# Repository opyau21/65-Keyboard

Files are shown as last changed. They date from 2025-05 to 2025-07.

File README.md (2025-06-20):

# 65% Keyboard Project Files
## Summary
  Creating a 65% Keyboard from scratch without any prior engineering knowledge.

## Next steps:
  * Write Software for ESP32 S3 Mini 1 and STM32

## To Do List:
* PCB: Finished, not yet tested
* Software (In Order)
  1. Keymaps
  2. OLED
  3. Fuel Gauge
  4. Magnetic Encoder
  5. Bluetooth
* Plate
* Foam
* Knob plastics
* Case
  1. Design
  2. Backweight
  3. OLED Screen
* Battery
* Program Software QMK/VIA

## BOM:
| Item # | Reference | Qty | Manufacturer | Vendor | Mfg Part # | Value | Description/Value | Package | Datasheet |
| --- | --- | --- | --- | --- | --- | --- | --- | --- | --- |
| 1 | C1, C11, C2, C3, C4, C5, C9 | 6 | Murata Electronics | Mouser | GRM155R71C103KA01J | 100nF | Multilayer Ceramic Capacitors MLCC - SMD/SMT 0.01 uF 16 VDC 10% 0402 X7R | 402 | ~ |
| 2 | C10,C15 | 2 | Murata Electronics | Mouser | GRM155R60J475ME47J | 4.7uF | Multilayer Ceramic Capacitors MLCC - SMD/SMT 4.7 uF 6.3 VDC 20% 0402 X5R | 402 | ~ |
| 3 | C8,C16 | 2 | Murata Electronics | Mouser | GRM1555C2A101GA01D | 10uF | Multilayer Ceramic Capacitors MLCC - SMD/SMT 0402 10uF 4VDC 20% X6S AEC-Q200 | 402 | ~ |
| 4 | C14 | 1 | Murata Electronics | Mouser | GRM1555C2A101GA01D | 100pF | Multilayer Ceramic Capacitors MLCC - SMD/SMT 100 pF 100 VDC 2% 0402 C0G (NP0) | 402 | ~ |
| 5 | C17 | 1 | Murata Electronics | Mouser | GRM155R61A104KA01J | 0.1uF | Multilayer Ceramic Capacitors MLCC - SMD/SMT 0.1 uF 10 VDC 10% 0402 X5R | 402 | https://www.mouser.com/datasheet/2/281/1/GRM155R61A104KA01_02A-1983866.pdf |
| 6 | C6, C7 | 2 | Murata Electronics | Mouser | GXT155R60J105KE01D | 1uF | Multilayer Ceramic Capacitors MLCC - SMD/SMT 0402 6.3VDC 1uF 10% X5R AEC-Q200 | 402 | |
| 7 | C20,C21,C22,C23,C24,C25,C26,C27,C28,C29,C30,C31,C32,C33,C34,C35,C36,C37,C38,C39,C40,C41,C42,C43,C44,C45,C46,C47,C49,C50,C51,C52,C53,C54,C55,C56,C57,C58,C59,C60,C61,C62,C63,C64,C65,C66,C67,C68,C69,C70,C71,C72,C73,C74,C75,C76,C77,C78,C79,C80,C81,C82,C83,C84,C85,C86,C87 | 67  | Murata Electronics | Mouser | GCM188R71C104KA37J | 0.1uF | Multilayer Ceramic Capacitors MLCC - SMD/SMT 0.1 uF 16 VDC 10% 0603 X7R AEC-Q200 | 603 | ~ |
| 8 | D1,D2,D3,D4,D5,D6,D7,D8,D9,D10,D11,D12,D13,D14,D15,D16,D17,D18,D19,D20,D21,D22,D23,D24,D25,D26,D27,D28,D30,D31,D32,D33,D34,D35,D36,D37,D38,D39,D40,D41,D42,D43,D44,D45,D46,D47,D48,D49,D50,D51,D52,D53,D54,D55,D56,D57,D58,D59,D60,D61,D62,D63,D64,D65,D66,D67,D68 | 67  | | Adafruit | | D_Small | Adafruit Accessories 1N4148 SMT SOD-123 Diodes - 100 Pack | | ~ |
| 9 | J1 | 1 | | AliExpress | | Conn_01x02 | | | ~ |
| 10 | J2 | 1 | | AliExpress | | Conn_01x04 | | | ~ |
| 11 | J3 | 1 | | AliExpress | | Conn_01x07 | | | ~ |
| 12 | LED1,LED2,LED3,LED4,LED5,LED6,LED7,LED8,LED9,LED10,LED11,LED12,LED13,LED14,LED15,LED16,LED17,LED18,LED19,LED20,LED21,LED22,LED23,LED24,LED25,LED26,LED27,LED28,LED30,LED31,LED32,LED33,LED34,LED35,LED36,LED37,LED38,LED39,LED40,LED41,LED42,LED43,LED44,LED45,LED46,LED47,LED48,LED49,LED50,LED51,LED52,LED53,LED54,LED55,LED56,LED57,LED58,LED59,LED60,LED61,LED62,LED63,LED64,LED65,LED66,LED67,LED68 | 67  | | AliExpress | | LED_SK6812MINI | | | https://cdn-shop.adafruit.com/product-files/2686/SK6812MINI_REV.01-1-2.pdf |
| 13 | R1, R11, R12, R17, R3, R5 | 6 | YAGEO | Mouser | RC0402JR-7D10KL | 10k | Thick Film Resistors - SMD 10 kOhms 62.5 mW 0402 5% | 402 | ~ |
| 14 | R6,R7,R8,R9,R10 | 5 | YAGEO | Mouser | [RC0402FR-7D4K7L](https://www.mouser.com/ProductDetail/YAGEO/RC0402FR-7D4K7L?qs=F5EMLAvA7ID7%2FFIVczkChg%3D%3D) | 4.7k | Thick Film Resistors - SMD 4.7 kOhms 62.5 mW 0402 1% | 402 | ~ |
| 15 | R15 | 1 | YAGEO | Mouser | | 1k | | 402 | ~ |
| 16 | R16 | 1 | YAGEO | Mouser | | 750 | | 402 | ~ |
| 17 | S1,S2,S3,S4,S5,S6,S7,S8,S9,S10,S11,S12,S13,S14,S16,S17,S18,S19,S20,S21,S22,S23,S24,S25,S26,S27,S31,S32,S33,S34,S35,S36,S37,S38,S39,S40,S41,S42,S43,S44,S45,S46,S47,S48,S49,S50,S51,S52,S53,S54,S56,S57,S61,S64,S65,S66,S71,S72 | 58  | | Cannonkeys | | Keyswitch | Kailh MX Hotswap Sockets - 110 Pack | | ~ |
| 18 | S15,S28 | 2 | | | | Keyswitch | | | ~ |
| 19 | S30,S55 | 2 | | | | Keyswitch | | | ~ |
| 20 | S58,S59,S60,S62,S63 | 5 | | | | Keyswitch | | | ~ |
| 21 | S67 | 1 | | Divinikey | | MX_stab | TX Stabilizers | | |
| 22 | S68,S69 | 2 | | | | MX_stab | | | |
| 23 | S70 | 1 | | | | MX_stab | | | |
| 24 | SW1,SW2 | 2 | E-Switch | Mouser | TL3342F450QG | SW_Push | Tactile Switches 50mA 12VDC Silver Gull Wing | | ~ |
| 25 | U1 | 1 | [Analog Devices / Maxim Integrated](https://www.mouser.com/manufacturer/maxim-integrated/) | Mouser | MAX17048G+T10 | MAX17048G_T10 | Battery Management 3 A 1-Cell/2-Cell Fuel Gauge with ModelGauge | | |
| 26 | U2 | 1 | Semtech | Mouser | SRV05-4.TCT | SRV05-4 | ESD Protection Diodes / TVS Diodes RAILCLAMP 4-LINE 5V 3K LFREE | | http://www.onsemi.com/pub/Collateral/SRV05-4-D.PDF |
| 27 | U3 | 1 | Azoteq | Mouser | IQS6243200DNR | IQS624-3200-DNR | Board Mount Motion & Position Sensors 2 x Capacitive, Hall rotation | | |
| 28 | U4 | 1 | EspressIf | Mouser | ESP32-S3-MINI-1-N8 | ESP32-S3-MINI-1-N8 | Multiprotocol Modules SMD module, ESP32-S3FN8, 8 MB SPI flash, PCB antenna | | https://www.espressif.com/sites/default/files/documentation/esp32-s3-mini-1_mini-1u_datasheet_en.pdf |
| 29 | U5 | 1 | | Mouser | BQ25185DLHR | BQ25185DLHR | | | |
| 30 | U6 | 1 | STMicroelectronics | Mouser | STM32F103RET6TR | STM32F103RETx | ARM Microcontrollers - MCU 32BIT Cortex M3 H/D Performance LINE | | https://www.st.com/resource/en/datasheet/stm32f103re.pdf |
| 31 | U7 | 1 | UMW | Digikey | AMS1117-3.3 | AMS1117-3.3 | 3.3V LDO Regulator | | |
| 32 | F1 | 1 | Bourns | Mouser | MF-FSMF050X-2 | MF-FSMF050X-2 | Resettable Fuses - PPTC 6V .5A-HD 40A MAX | | |
| 33 | | 1 | | Amazon/AliExpress | | 5000 mah | 5000 mah Lithium Ion Recharable Battery | | |
| 34 | | 1 | | AliExpress | | 01x07 JST PH Wire  | 01x07 JST PH Wire | | |
| 35 | | 1 | aio3 | Cannonkeys | | | Unified Daughterboard | | |
| 36 | | 1 | Waveshare | Amazon | | 128 x 128 | 1.5 inch 128 x 128 RGB OLED Screen | | |
| 37 | | 1 | Logitech | AliExpress | | | Logitech MX Master 3s Side Scroll Component | | |

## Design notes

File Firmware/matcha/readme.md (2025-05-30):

# matcha

matcha

*A short description of the keyboard/project*

* Keyboard Maintainer: [Oliver Yau](https://github.com/opyau21)
* Hardware Supported: *The PCBs, controllers supported*
* Hardware Availability: *Links to where you can find this hardware*

Make example for this keyboard (after setting up your build environment):

    make matcha:default

Flashing example for this keyboard:

    make matcha:default:flash

See the [build environment setup](https://docs.qmk.fm/#/getting_started_build_tools) and the [make instructions](https://docs.qmk.fm/#/getting_started_make_guide) for more information. Brand new to QMK? Start with our [Complete Newbs Guide](https://docs.qmk.fm/#/newbs).

## Bootloader

Enter the bootloader in 3 ways:

* **Bootmagic reset**: Hold down the key at (0,0) in the matrix (usually the top left key or Escape) and plug in the keyboard
* **Physical reset button**: Briefly press the button on the back of the PCB - some may have pads you must short instead
* **Keycode in layout**: Press the key mapped to `QK_BOOT` if it is available

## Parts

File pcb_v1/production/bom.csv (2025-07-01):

Designator | Footprint | Quantity | Value | LCSC Part #
C1, C11, C2, C3, C4, C5, C9 | CAPC1005X55N | 7 | 100nF | C49678
C10, C15 | CAPC1005X55N | 2 | 4.7uF | C49678
C14 | CAPC1005X55N | 1 | 100pF | C49678
C16, C8 | CAPC1005X55N | 2 | 10uF | C49678
C17 | CAPC1005X55N | 1 | 0.1uF | C49678
C18, C19 | CAPC1005X55N | 2 | 1uF | C49678
C20, C21, C22, C23, C24, C25, C26, C27, C28, C29, C30, C31, C32, C33, C34, C35, C36, C37, C38, C39, C40, C41, C42, C43, C44, C45, C46, C47, C49, C50, C51, C52, C53, C54, C55, C56, C57, C58, C59, C60, C61, C62, C63, C64, C65, C66, C67, C68, C69, C70, C71, C72, C73, C74, C75, C76, C77, C78, C79, C80, C81, C82, C83, C84, C85, C86, C87 | CAPC1608X90N | 67 | 100nF
C6, C7 | CAPC1005X55N | 2 | 4.7uF
D1, D10, D11, D12, D13, D14, D15, D16, D17, D18, D19, D2, D20, D21, D22, D23, D24, D25, D26, D27, D28, D3, D30, D31, D32, D33, D34, D35, D36, D37, D38, D39, D4, D40, D41, D42, D43, D44, D45, D46, D47, D48, D49, D5, D50, D51, D52, D53, D54, D55, D56, D57, D58, D59, D6, D60, D61, D62, D63, D64, D65, D66, D67, D68, D7, D8, D9 | Diode_SOD-123 | 67 | D_Small
F1 | 0603 | 1 | 500mA
J1 | JST_PH_S2B-PH-SM4-TB_1x02-1MP_P2.00mm_Horizontal | 1 | Conn_01x02
J2 | JST_SH_SM04B-SRSS-TB_1x04-1MP_P1.00mm_Horizontal | 1 | Conn_01x04
J3 | JST_PH_S7B-PH-SM4-TB_1x07-1MP_P2.00mm_Horizontal | 1 | Conn_01x07
LED1, LED10, LED11, LED12, LED13, LED14, LED15, LED16, LED17, LED18, LED19, LED2, LED20, LED21, LED22, LED23, LED24, LED25, LED26, LED27, LED28, LED3, LED30, LED31, LED32, LED33, LED34, LED35, LED36, LED37, LED38, LED39, LED4, LED40, LED41, LED42, LED43, LED44, LED45, LED46, LED47, LED48, LED49, LED5, LED50, LED51, LED52, LED53, LED54, LED55, LED56, LED57, LED58, LED59, LED6, LED60, LED61, LED62, LED63, LED64, LED65, LED66, LED67, LED68, LED7, LED8, LED9 | LED_SK6812MINI | 67 | LED_SK6812MINI | C5149201
R1, R11, R12, R17, R2, R3, R4, R5 | RESC1005X40N | 8 | 10k
R10, R6, R7, R8, R9 | RESC1005X40N | 5 | 4.7k
R15 | RESC1005X40N | 1 | 1k
R16 | RESC1005X40N | 1 | 750
S1, S10, S11, S12, S13, S14, S16, S17, S18, S19, S2, S20, S21, S22, S23, S24, S25, S26, S27, S3, S31, S32, S33, S34, S35, S36, S37, S38, S39, S4, S40, S41, S42, S43, S44, S45, S46, S47, S48, S49, S5, S50, S51, S52, S53, S54, S56, S57, S6, S61, S64, S65, S66, S7, S71, S72, S8, S9 | SW_MX_HS_CPG151101S11_1u | 58 | Keyswitch
S15, S28 | SW_MX_HS_CPG151101S11_1.5u | 2 | Keyswitch
S30, S55 | SW_MX_HS_CPG151101S11_1.75u | 2 | Keyswitch
S58, S59, S60, S62, S63 | SW_MX_HS_CPG151101S11_1.25u | 5 | Keyswitch
S67 | STAB_MX_P_2u | 1 | MX_stab
S68, S69 | STAB_MX_2.25u | 2 | MX_stab
S70 | STAB_MX_P_6.25u | 1 | MX_stab
SW1, SW2 | Button_TL3342 | 2 | SW_Push
U1 | SON50P200X200X80-9N | 1 | MAX17048G_T10
U2 | SOT-23-6 | 1 | SRV05-4 | C85364
U3 | SON50P300X300X80-11N | 1 | IQS624-3200-DNR
U4 | XCVR_ESP32-S3-MINI-1-N8 | 1 | ESP32-S3-MINI-1
U5 | WSON10_DLH_TEX | 1 | BQ25185DLHR
U6 | LQFP-64_10x10mm_P0.5mm | 1 | STM32F103RETx
U7 | SOT229P700X180-4N | 1 | AMS1117-3.3

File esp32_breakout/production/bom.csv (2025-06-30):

Designator | Footprint | Quantity | Value | LCSC Part #
3.3V, EN, GND1, GPIO0, RX, TX | TestPoint_THTPad_D2.0mm_Drill1.0mm | 6 | TestPoint
C8 | CAPC1005X55N | 1 | 10uF | C49678
C9 | CAPC1005X55N | 1 | 100nF | C49678
R1, R2 | RESC1005X40N | 2 | 10k
U4 | XCVR_ESP32-S3-MINI-1-N8 | 1 | ESP32-S3-MINI-1

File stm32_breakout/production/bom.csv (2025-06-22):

Designator | Footprint | Quantity | Value | LCSC Part #
3.3V, BOOT0, GND, NRST, RX, TX | TestPoint_THTPad_D2.0mm_Drill1.0mm | 6 | TestPoint
C1, C11, C2, C3, C4, C5 | CAPC1005X55N | 6 | 100nF | C49678
C10 | CAPC1005X55N | 1 | 4.7uF | C49678
R1, R12 | RESC1005X40N | 2 | 10k
U6 | LQFP-64_10x10mm_P0.5mm | 1 | STM32F103RETx

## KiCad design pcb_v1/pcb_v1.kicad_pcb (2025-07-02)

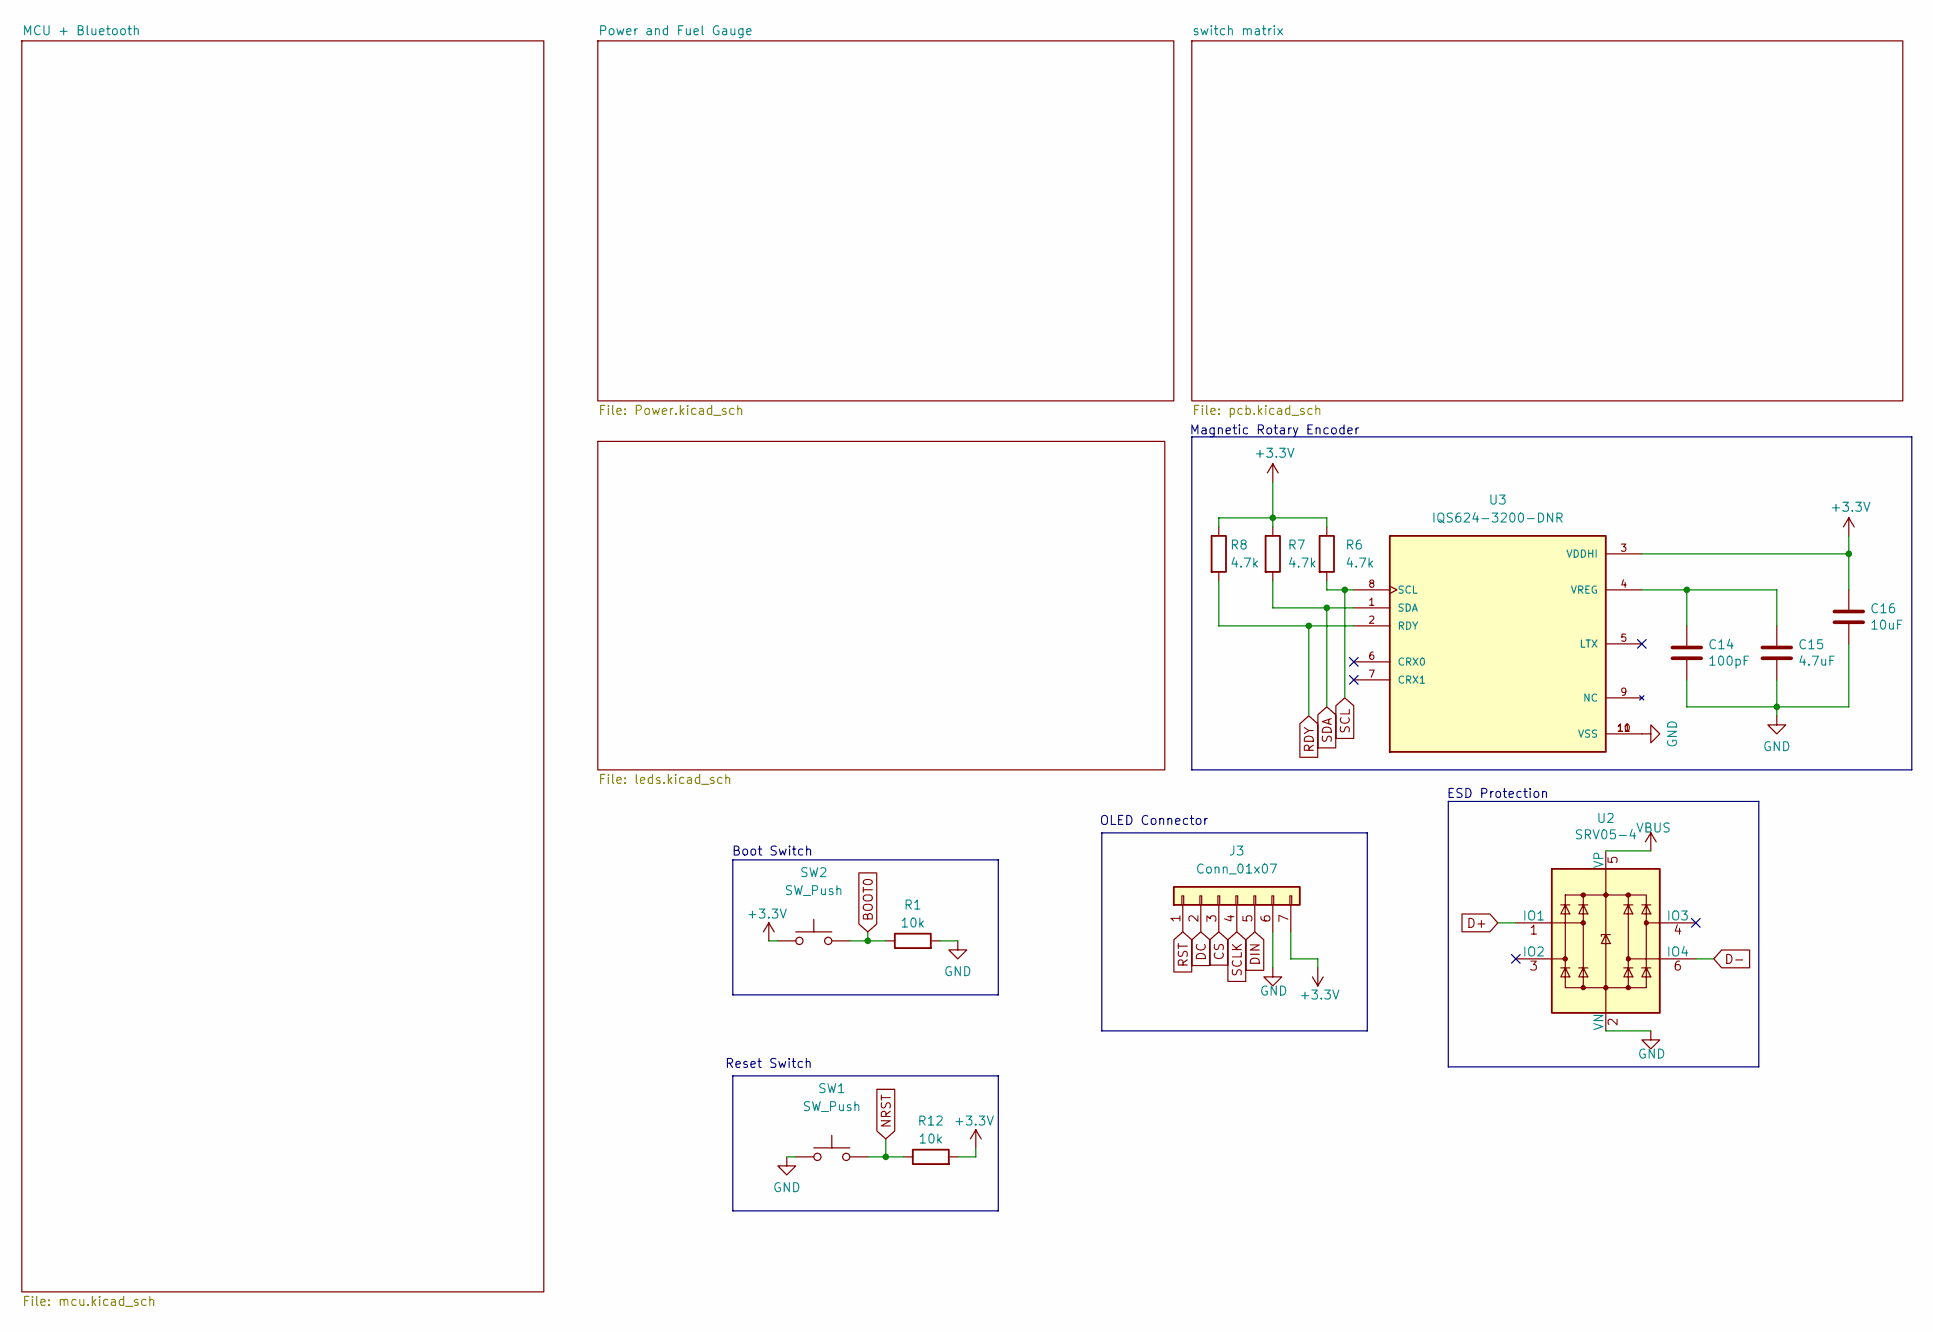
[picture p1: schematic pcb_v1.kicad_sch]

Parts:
C14: 100pF; CAPC1005X55N; LCSC Part # C49678
C15: 4.7uF; CAPC1005X55N; LCSC Part # C49678
C16: 10uF; CAPC1005X55N; LCSC Part # C49678
J3: Conn_01x07; JST_PH_S7B-PH-SM4-TB_1x07-1MP_P2.00mm_Horizontal
R1, R12: 10k; RESC1005X40N
R6, R7, R8: 4.7k; RESC1005X40N
SW1, SW2: SW_Push; Button_TL3342
U2: SRV05-4; SOT-23-6; LCSC Part # C85364
U3: IQS624-3200-DNR; SON50P300X300X80-11N; PARTREV 2.04

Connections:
+3.3V: C16.1, J3.7, R6.1, R7.1, R8.1, R12.2, SW2.1, U3.3 (VDDHI); also elsewhere on the board
BOOT0: R1.1, SW2.2; also elsewhere on the board
CS: J3.3; also elsewhere on the board
D+: U2.1 (IO1); also elsewhere on the board
D-: U2.6 (IO4); also elsewhere on the board
DC: J3.2; also elsewhere on the board
DIN: J3.5; also elsewhere on the board
GND: C14.2, C15.2, C16.2, J3.6, R1.2, SW1.1, U2.2 (VN), U3.10 (VSS), U3.11 (VSS); also elsewhere on the board
NRST: R12.1, SW1.2; also elsewhere on the board
unnamed: C14.1, C15.1, U3.4 (VREG)
RDY: R8.2, U3.2 (RDY); also elsewhere on the board
RST: J3.1; also elsewhere on the board
SCL: R6.2, U3.8 (SCL); also elsewhere on the board
SCLK: J3.4; also elsewhere on the board
SDA: R7.2, U3.1 (SDA); also elsewhere on the board
VBUS: U2.5 (VP); also elsewhere on the board

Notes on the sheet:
OLED Connector
Boot Switch
ESD Protection
Magnetic Rotary Encoder
Reset Switch

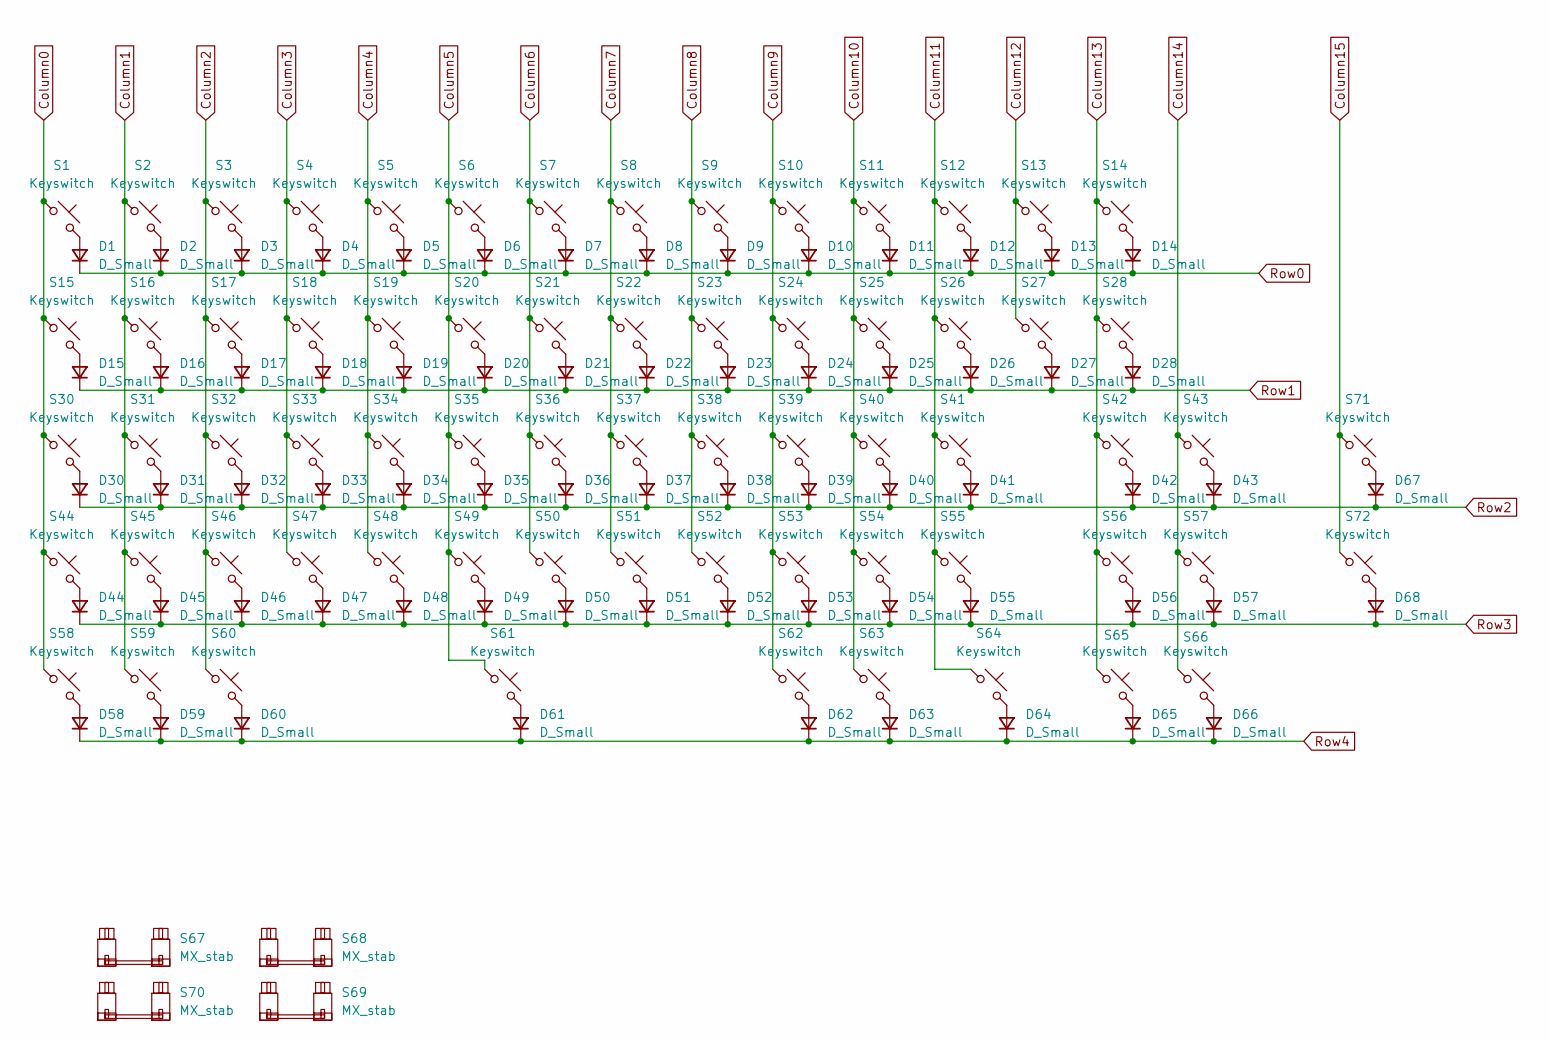
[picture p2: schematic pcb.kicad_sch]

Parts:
D1, D2, D3, D4, D5, D6, D7, D8, D9, D10, D11, D12, D13, D14, D15, D16, D17, D18, D19, D20, D21, D22, D23, D24, D25, D26, D27, D28, D30, D31, D32, D33, D34, D35, D36, D37, D38, D39, D40, D41, D42, D43, D44, D45, D46, D47, D48, D49, D50, D51, D52, D53, D54, D55, D56, D57, D58, D59, D60, D61, D62, D63, D64, D65, D66, D67, D68: D_Small; Diode_SOD-123
S1, S2, S3, S4, S5, S6, S7, S8, S9, S10, S11, S12, S13, S14, S16, S17, S18, S19, S20, S21, S22, S23, S24, S25, S26, S27, S31, S32, S33, S34, S35, S36, S37, S38, S39, S40, S41, S42, S43, S44, S45, S46, S47, S48, S49, S50, S51, S52, S53, S54, S56, S57, S61, S64, S65, S66, S71, S72: Keyswitch; SW_MX_HS_CPG151101S11_1u
S15, S28: Keyswitch; SW_MX_HS_CPG151101S11_1.5u
S30, S55: Keyswitch; SW_MX_HS_CPG151101S11_1.75u
S58, S59, S60, S62, S63: Keyswitch; SW_MX_HS_CPG151101S11_1.25u
S67: MX_stab; STAB_MX_P_2u
S68, S69: MX_stab; STAB_MX_2.25u
S70: MX_stab; STAB_MX_P_6.25u

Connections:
Column0: S1.1, S15.1, S30.1, S44.1, S58.1; also elsewhere on the board
Column1: S2.1, S16.1, S31.1, S45.1, S59.1; also elsewhere on the board
Column2: S3.1, S17.1, S32.1, S46.1, S60.1; also elsewhere on the board
Column3: S4.1, S18.1, S33.1, S47.1; also elsewhere on the board
Column4: S5.1, S19.1, S34.1, S48.1; also elsewhere on the board
Column5: S6.1, S20.1, S35.1, S49.1, S61.1; also elsewhere on the board
Column6: S7.1, S21.1, S36.1, S50.1; also elsewhere on the board
Column7: S8.1, S22.1, S37.1, S51.1; also elsewhere on the board
Column8: S9.1, S23.1, S38.1, S52.1; also elsewhere on the board
Column9: S10.1, S24.1, S39.1, S53.1, S62.1; also elsewhere on the board
Column10: S11.1, S25.1, S40.1, S54.1, S63.1; also elsewhere on the board
Column11: S12.1, S26.1, S41.1, S55.1, S64.1; also elsewhere on the board
Column12: S13.1, S27.1; also elsewhere on the board
Column13: S14.1, S28.1, S42.1, S56.1, S65.1; also elsewhere on the board
Column14: S43.1, S57.1, S66.1; also elsewhere on the board
Column15: S71.1, S72.1; also elsewhere on the board
unnamed: D1.2 (A), S1.2
unnamed: D2.2 (A), S2.2
unnamed: D3.2 (A), S3.2
unnamed: D4.2 (A), S4.2
unnamed: D5.2 (A), S5.2
unnamed: D6.2 (A), S6.2
unnamed: D7.2 (A), S7.2
unnamed: D8.2 (A), S8.2
unnamed: D9.2 (A), S9.2
unnamed: D10.2 (A), S10.2
unnamed: D11.2 (A), S11.2
unnamed: D12.2 (A), S12.2
unnamed: D13.2 (A), S13.2
unnamed: D14.2 (A), S14.2
unnamed: D15.2 (A), S15.2
unnamed: D16.2 (A), S16.2
unnamed: D17.2 (A), S17.2
unnamed: D18.2 (A), S18.2
unnamed: D19.2 (A), S19.2
unnamed: D20.2 (A), S20.2
unnamed: D21.2 (A), S21.2
unnamed: D22.2 (A), S22.2
unnamed: D23.2 (A), S23.2
unnamed: D24.2 (A), S24.2
unnamed: D25.2 (A), S25.2
unnamed: D26.2 (A), S26.2
unnamed: D27.2 (A), S27.2
unnamed: D28.2 (A), S28.2
unnamed: D30.2 (A), S30.2
unnamed: D31.2 (A), S31.2
unnamed: D32.2 (A), S32.2
unnamed: D33.2 (A), S33.2
unnamed: D34.2 (A), S34.2
unnamed: D35.2 (A), S35.2
unnamed: D36.2 (A), S36.2
unnamed: D37.2 (A), S37.2
unnamed: D38.2 (A), S38.2
unnamed: D39.2 (A), S39.2
unnamed: D40.2 (A), S40.2
unnamed: D41.2 (A), S41.2
unnamed: D42.2 (A), S42.2
unnamed: D43.2 (A), S43.2
unnamed: D44.2 (A), S44.2
unnamed: D45.2 (A), S45.2
unnamed: D46.2 (A), S46.2
unnamed: D47.2 (A), S47.2
unnamed: D48.2 (A), S48.2
unnamed: D49.2 (A), S49.2
unnamed: D50.2 (A), S50.2
unnamed: D51.2 (A), S51.2
unnamed: D52.2 (A), S52.2
unnamed: D53.2 (A), S53.2
unnamed: D54.2 (A), S54.2
unnamed: D55.2 (A), S55.2
unnamed: D56.2 (A), S56.2
unnamed: D57.2 (A), S57.2
unnamed: D58.2 (A), S58.2
unnamed: D59.2 (A), S59.2
unnamed: D60.2 (A), S60.2
unnamed: D61.2 (A), S61.2
unnamed: D62.2 (A), S62.2
unnamed: D63.2 (A), S63.2
unnamed: D64.2 (A), S64.2
unnamed: D65.2 (A), S65.2
unnamed: D66.2 (A), S66.2
unnamed: D67.2 (A), S71.2
unnamed: D68.2 (A), S72.2
Row0: D1.1 (K), D2.1 (K), D3.1 (K), D4.1 (K), D5.1 (K), D6.1 (K), D7.1 (K), D8.1 (K), D9.1 (K), D10.1 (K), D11.1 (K), D12.1 (K), D13.1 (K), D14.1 (K); also elsewhere on the board
Row1: D15.1 (K), D16.1 (K), D17.1 (K), D18.1 (K), D19.1 (K), D20.1 (K), D21.1 (K), D22.1 (K), D23.1 (K), D24.1 (K), D25.1 (K), D26.1 (K), D27.1 (K), D28.1 (K); also elsewhere on the board
Row2: D30.1 (K), D31.1 (K), D32.1 (K), D33.1 (K), D34.1 (K), D35.1 (K), D36.1 (K), D37.1 (K), D38.1 (K), D39.1 (K), D40.1 (K), D41.1 (K), D42.1 (K), D43.1 (K), D67.1 (K); also elsewhere on the board
Row3: D44.1 (K), D45.1 (K), D46.1 (K), D47.1 (K), D48.1 (K), D49.1 (K), D50.1 (K), D51.1 (K), D52.1 (K), D53.1 (K), D54.1 (K), D55.1 (K), D56.1 (K), D57.1 (K), D68.1 (K); also elsewhere on the board
Row4: D58.1 (K), D59.1 (K), D60.1 (K), D61.1 (K), D62.1 (K), D63.1 (K), D64.1 (K), D65.1 (K), D66.1 (K); also elsewhere on the board

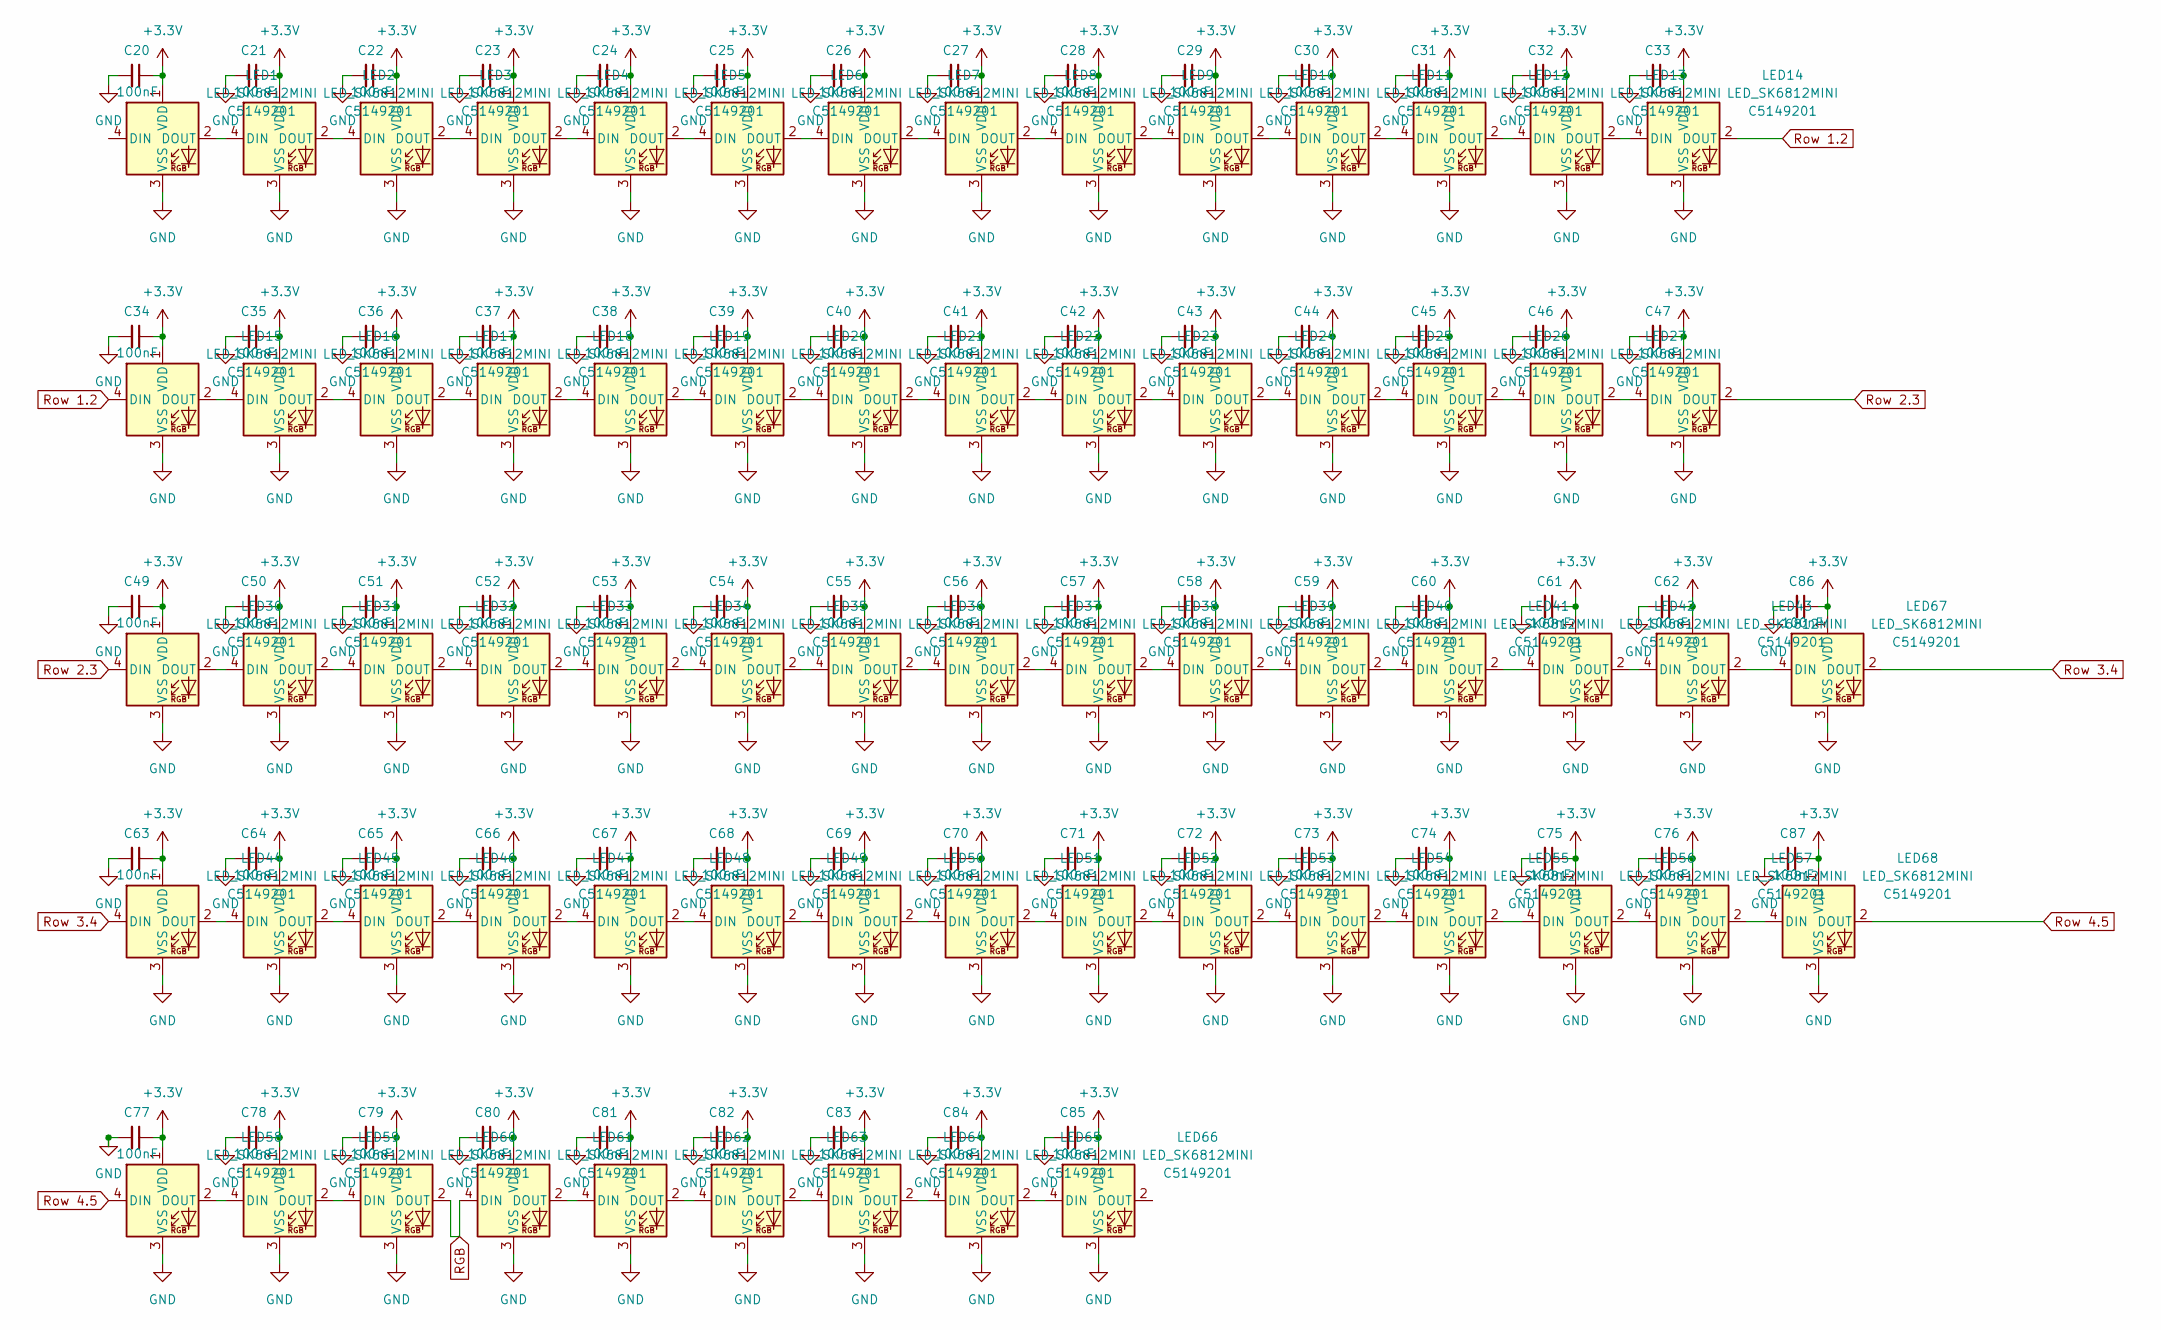
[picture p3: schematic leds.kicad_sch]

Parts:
C20, C21, C22, C23, C24, C25, C26, C27, C28, C29, C30, C31, C32, C33, C34, C35, C36, C37, C38, C39, C40, C41, C42, C43, C44, C45, C46, C47, C49, C50, C51, C52, C53, C54, C55, C56, C57, C58, C59, C60, C61, C62, C63, C64, C65, C66, C67, C68, C69, C70, C71, C72, C73, C74, C75, C76, C77, C78, C79, C80, C81, C82, C83, C84, C85, C86, C87: 100nF; CAPC1608X90N
LED1, LED2, LED3, LED4, LED5, LED6, LED7, LED8, LED9, LED10, LED11, LED12, LED13, LED14, LED15, LED16, LED17, LED18, LED19, LED20, LED21, LED22, LED23, LED24, LED25, LED26, LED27, LED28, LED30, LED31, LED32, LED33, LED34, LED35, LED36, LED37, LED38, LED39, LED40, LED41, LED42, LED43, LED44, LED45, LED46, LED47, LED48, LED49, LED50, LED51, LED52, LED53, LED54, LED55, LED56, LED57, LED58, LED59, LED60, LED61, LED62, LED63, LED64, LED65, LED66, LED67, LED68: LED_SK6812MINI; LCSC C5149201

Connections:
+3.3V: C20.1, C21.1, C22.1, C23.1, C24.1, C25.1, C26.1, C27.1, C28.1, C29.1, C30.1, C31.1, C32.1, C33.1, C34.1, C35.1, C36.1, C37.1, C38.1, C39.1, C40.1, C41.1, C42.1, C43.1, C44.1, C45.1, C46.1, C47.1, C49.1, C50.1, C51.1, C52.1, C53.1, C54.1, C55.1, C56.1, C57.1, C58.1, C59.1, C60.1, C61.1, C62.1, C63.1, C64.1, C65.1, C66.1, C67.1, C68.1, C69.1, C70.1, C71.1, C72.1, C73.1, C74.1, C75.1, C76.1, C77.1, C78.1, C79.1, C80.1, C81.1, C82.1, C83.1, C84.1, C85.1, C86.1, C87.1, LED1.1 (VDD), LED2.1 (VDD), LED3.1 (VDD), LED4.1 (VDD), LED5.1 (VDD), LED6.1 (VDD), LED7.1 (VDD), LED8.1 (VDD), LED9.1 (VDD), LED10.1 (VDD), LED11.1 (VDD), LED12.1 (VDD), LED13.1 (VDD), LED14.1 (VDD), LED15.1 (VDD), LED16.1 (VDD), LED17.1 (VDD), LED18.1 (VDD), LED19.1 (VDD), LED20.1 (VDD), LED21.1 (VDD), LED22.1 (VDD), LED23.1 (VDD), LED24.1 (VDD), LED25.1 (VDD), LED26.1 (VDD), LED27.1 (VDD), LED28.1 (VDD), LED30.1 (VDD), LED31.1 (VDD), LED32.1 (VDD), LED33.1 (VDD), LED34.1 (VDD), LED35.1 (VDD), LED36.1 (VDD), LED37.1 (VDD), LED38.1 (VDD), LED39.1 (VDD), LED40.1 (VDD), LED41.1 (VDD), LED42.1 (VDD), LED43.1 (VDD), LED44.1 (VDD), LED45.1 (VDD), LED46.1 (VDD), LED47.1 (VDD), LED48.1 (VDD), LED49.1 (VDD), LED50.1 (VDD), LED51.1 (VDD), LED52.1 (VDD), LED53.1 (VDD), LED54.1 (VDD), LED55.1 (VDD), LED56.1 (VDD), LED57.1 (VDD), LED58.1 (VDD), LED59.1 (VDD), LED60.1 (VDD), LED61.1 (VDD), LED62.1 (VDD), LED63.1 (VDD), LED64.1 (VDD), LED65.1 (VDD), LED66.1 (VDD), LED67.1 (VDD), LED68.1 (VDD); also elsewhere on the board
GND: C20.2, C21.2, C22.2, C23.2, C24.2, C25.2, C26.2, C27.2, C28.2, C29.2, C30.2, C31.2, C32.2, C33.2, C34.2, C35.2, C36.2, C37.2, C38.2, C39.2, C40.2, C41.2, C42.2, C43.2, C44.2, C45.2, C46.2, C47.2, C49.2, C50.2, C51.2, C52.2, C53.2, C54.2, C55.2, C56.2, C57.2, C58.2, C59.2, C60.2, C61.2, C62.2, C63.2, C64.2, C65.2, C66.2, C67.2, C68.2, C69.2, C70.2, C71.2, C72.2, C73.2, C74.2, C75.2, C76.2, C77.2, C78.2, C79.2, C80.2, C81.2, C82.2, C83.2, C84.2, C85.2, C86.2, C87.2, LED1.3 (VSS), LED2.3 (VSS), LED3.3 (VSS), LED4.3 (VSS), LED5.3 (VSS), LED6.3 (VSS), LED7.3 (VSS), LED8.3 (VSS), LED9.3 (VSS), LED10.3 (VSS), LED11.3 (VSS), LED12.3 (VSS), LED13.3 (VSS), LED14.3 (VSS), LED15.3 (VSS), LED16.3 (VSS), LED17.3 (VSS), LED18.3 (VSS), LED19.3 (VSS), LED20.3 (VSS), LED21.3 (VSS), LED22.3 (VSS), LED23.3 (VSS), LED24.3 (VSS), LED25.3 (VSS), LED26.3 (VSS), LED27.3 (VSS), LED28.3 (VSS), LED30.3 (VSS), LED31.3 (VSS), LED32.3 (VSS), LED33.3 (VSS), LED34.3 (VSS), LED35.3 (VSS), LED36.3 (VSS), LED37.3 (VSS), LED38.3 (VSS), LED39.3 (VSS), LED40.3 (VSS), LED41.3 (VSS), LED42.3 (VSS), LED43.3 (VSS), LED44.3 (VSS), LED45.3 (VSS), LED46.3 (VSS), LED47.3 (VSS), LED48.3 (VSS), LED49.3 (VSS), LED50.3 (VSS), LED51.3 (VSS), LED52.3 (VSS), LED53.3 (VSS), LED54.3 (VSS), LED55.3 (VSS), LED56.3 (VSS), LED57.3 (VSS), LED58.3 (VSS), LED59.3 (VSS), LED60.3 (VSS), LED61.3 (VSS), LED62.3 (VSS), LED63.3 (VSS), LED64.3 (VSS), LED65.3 (VSS), LED66.3 (VSS), LED67.3 (VSS), LED68.3 (VSS); also elsewhere on the board
unnamed: LED1.2 (DOUT), LED2.4 (DIN)
unnamed: LED2.2 (DOUT), LED3.4 (DIN)
unnamed: LED3.2 (DOUT), LED4.4 (DIN)
unnamed: LED4.2 (DOUT), LED5.4 (DIN)
unnamed: LED5.2 (DOUT), LED6.4 (DIN)
unnamed: LED6.2 (DOUT), LED7.4 (DIN)
unnamed: LED7.2 (DOUT), LED8.4 (DIN)
unnamed: LED8.2 (DOUT), LED9.4 (DIN)
unnamed: LED9.2 (DOUT), LED10.4 (DIN)
unnamed: LED10.2 (DOUT), LED11.4 (DIN)
unnamed: LED11.2 (DOUT), LED12.4 (DIN)
unnamed: LED12.2 (DOUT), LED13.4 (DIN)
unnamed: LED13.2 (DOUT), LED14.4 (DIN)
unnamed: LED15.2 (DOUT), LED16.4 (DIN)
unnamed: LED16.2 (DOUT), LED17.4 (DIN)
unnamed: LED17.2 (DOUT), LED18.4 (DIN)
unnamed: LED18.2 (DOUT), LED19.4 (DIN)
unnamed: LED19.2 (DOUT), LED20.4 (DIN)
unnamed: LED20.2 (DOUT), LED21.4 (DIN)
unnamed: LED21.2 (DOUT), LED22.4 (DIN)
unnamed: LED22.2 (DOUT), LED23.4 (DIN)
unnamed: LED23.2 (DOUT), LED24.4 (DIN)
unnamed: LED24.2 (DOUT), LED25.4 (DIN)
unnamed: LED25.2 (DOUT), LED26.4 (DIN)
unnamed: LED26.2 (DOUT), LED27.4 (DIN)
unnamed: LED27.2 (DOUT), LED28.4 (DIN)
unnamed: LED30.2 (DOUT), LED31.4 (DIN)
unnamed: LED31.2 (DOUT), LED32.4 (DIN)
unnamed: LED32.2 (DOUT), LED33.4 (DIN)
unnamed: LED33.2 (DOUT), LED34.4 (DIN)
unnamed: LED34.2 (DOUT), LED35.4 (DIN)
unnamed: LED35.2 (DOUT), LED36.4 (DIN)
unnamed: LED36.2 (DOUT), LED37.4 (DIN)
unnamed: LED37.2 (DOUT), LED38.4 (DIN)
unnamed: LED38.2 (DOUT), LED39.4 (DIN)
unnamed: LED39.2 (DOUT), LED40.4 (DIN)
unnamed: LED40.2 (DOUT), LED41.4 (DIN)
unnamed: LED41.2 (DOUT), LED42.4 (DIN)
unnamed: LED42.2 (DOUT), LED43.4 (DIN)
unnamed: LED43.2 (DOUT), LED67.4 (DIN)
unnamed: LED44.2 (DOUT), LED45.4 (DIN)
unnamed: LED45.2 (DOUT), LED46.4 (DIN)
unnamed: LED46.2 (DOUT), LED47.4 (DIN)
unnamed: LED47.2 (DOUT), LED48.4 (DIN)
unnamed: LED48.2 (DOUT), LED49.4 (DIN)
unnamed: LED49.2 (DOUT), LED50.4 (DIN)
unnamed: LED50.2 (DOUT), LED51.4 (DIN)
unnamed: LED51.2 (DOUT), LED52.4 (DIN)
unnamed: LED52.2 (DOUT), LED53.4 (DIN)
unnamed: LED53.2 (DOUT), LED54.4 (DIN)
unnamed: LED54.2 (DOUT), LED55.4 (DIN)
unnamed: LED55.2 (DOUT), LED56.4 (DIN)
unnamed: LED56.2 (DOUT), LED57.4 (DIN)
unnamed: LED57.2 (DOUT), LED68.4 (DIN)
unnamed: LED58.2 (DOUT), LED59.4 (DIN)
unnamed: LED59.2 (DOUT), LED60.4 (DIN)
unnamed: LED61.2 (DOUT), LED62.4 (DIN)
unnamed: LED62.2 (DOUT), LED63.4 (DIN)
unnamed: LED63.2 (DOUT), LED64.4 (DIN)
unnamed: LED64.2 (DOUT), LED65.4 (DIN)
unnamed: LED65.2 (DOUT), LED66.4 (DIN)
RGB: LED60.2 (DOUT), LED61.4 (DIN); also elsewhere on the board
Row 1.2: LED14.2 (DOUT), LED15.4 (DIN)
Row 2.3: LED28.2 (DOUT), LED30.4 (DIN)
Row 3.4: LED44.4 (DIN), LED67.2 (DOUT)
Row 4.5: LED58.4 (DIN), LED68.2 (DOUT)

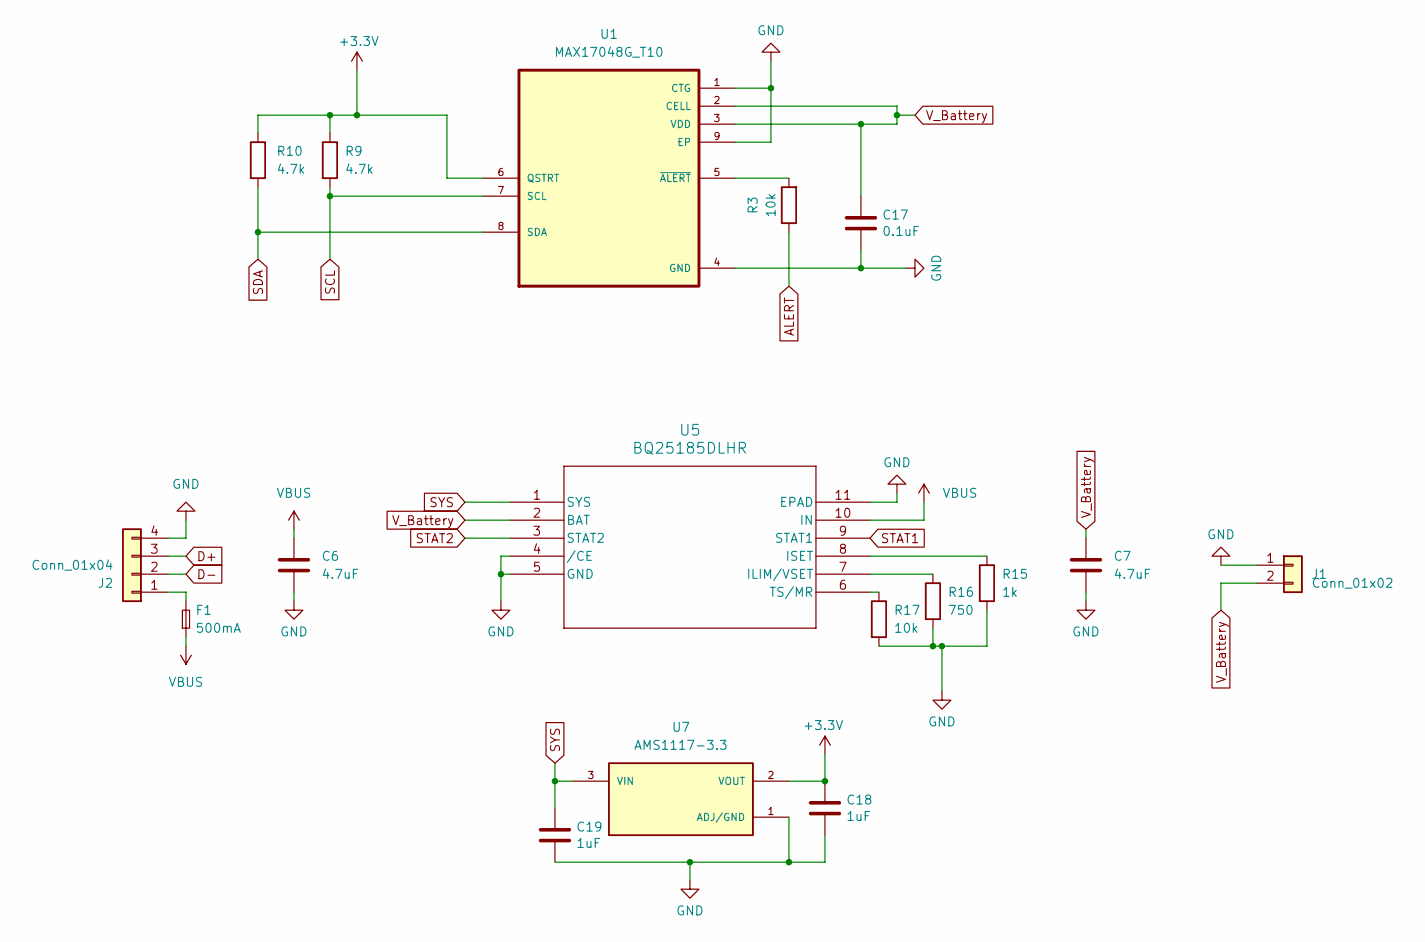
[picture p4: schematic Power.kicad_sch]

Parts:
C6, C7: 4.7uF; CAPC1005X55N
C17: 0.1uF; CAPC1005X55N; LCSC Part # C49678
C18, C19: 1uF; CAPC1005X55N; LCSC Part # C49678
F1: 500mA; Fuse_0603_1608Metric
J1: Conn_01x02; JST_PH_S2B-PH-SM4-TB_1x02-1MP_P2.00mm_Horizontal
J2: Conn_01x04; JST_SH_SM04B-SRSS-TB_1x04-1MP_P1.00mm_Horizontal
R3, R17: 10k; RESC1005X40N
R9, R10: 4.7k; RESC1005X40N
R15: 1k; RESC1005X40N
R16: 750; RESC1005X40N
U1: MAX17048G_T10; SON50P200X200X80-9N
U5: BQ25185DLHR; WSON10_DLH_TEX
U7: AMS1117-3.3; SOT229P700X180-4N; PARTREV NA

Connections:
+3.3V: C18.1, R9.1, R10.1, U1.6 (QSTRT), U7.2 (VOUT), U7.4; also elsewhere on the board
ALERT: R3.1; also elsewhere on the board
D+: J2.3; also elsewhere on the board
D-: J2.2; also elsewhere on the board
GND: C6.2, C7.2, C17.2, C18.2, C19.2, J1.1, J2.4, R15.2, R16.2, R17.2, U1.1 (CTG), U1.4 (GND), U1.9 (EP), U5.4 (/CE), U5.5 (GND), U5.11 (EPAD), U7.1 (ADJ/GND); also elsewhere on the board
unnamed: F1.2, J2.1
unnamed: R3.2, U1.5 (~ALERT)
unnamed: R16.1, U5.7 (ILIM/VSET)
unnamed: R15.1, U5.8 (ISET)
unnamed: R17.1, U5.6 (TS/MR)
SCL: R9.2, U1.7 (SCL); also elsewhere on the board
SDA: R10.2, U1.8 (SDA); also elsewhere on the board
STAT1: U5.9 (STAT1); also elsewhere on the board
STAT2: U5.3 (STAT2); also elsewhere on the board
SYS: C19.1, U5.1 (SYS), U7.3 (VIN)
VBUS: C6.1, F1.1, U5.10 (IN); also elsewhere on the board
V_Battery: C7.1, C17.1, J1.2, U1.2 (CELL), U1.3 (VDD), U5.2 (BAT)

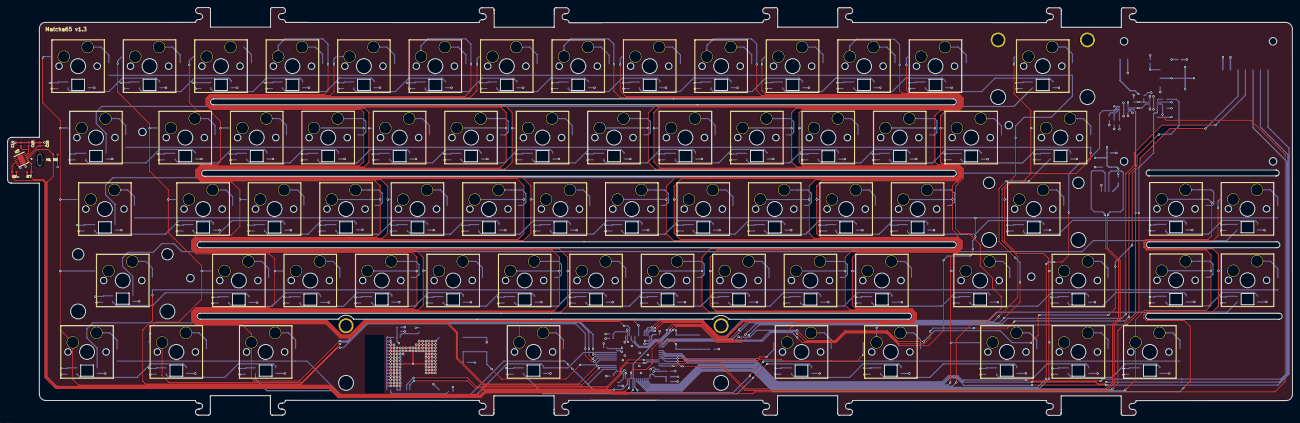
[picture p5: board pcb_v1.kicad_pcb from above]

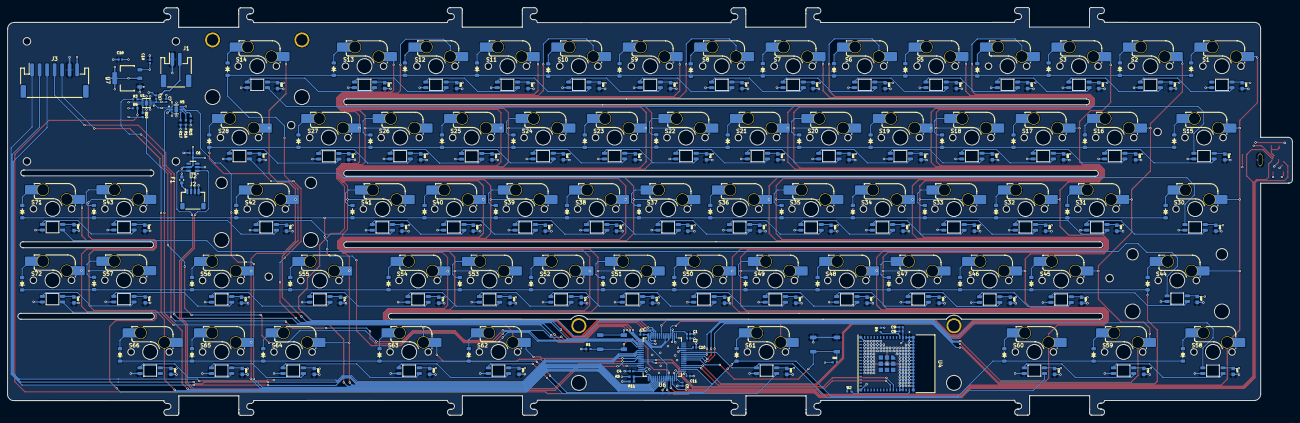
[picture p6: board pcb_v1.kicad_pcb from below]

Board: 4 copper layers, 342.6 x 108.7 mm, 318 parts (309 on the bottom side), 185 nets.

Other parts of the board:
C1, C2, C3, C4, C5, C9, C11: 100nF; CAPC1005X55N
C8: 10uF; CAPC1005X55N
C10: 4.7uF; CAPC1005X55N
H1: MountingHole_2.2mm_M2_DIN965_Pad
R2, R4, R5, R11: 10k; RESC1005X40N
U4: ESP32-S3-MINI-1; XCVR_ESP32-S3-MINI-1-N8
U6: STM32F103RETx; LQFP-64_10x10mm_P0.5mm

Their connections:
+3.3V: C1.1, C2.1, C3.1, C4.1, C5.1, C8.1, C9.1, C10.1, C11.1, R2.2, R4.2, U4.3 (3V3), U6.1 (VBAT), U6.13 (VDDA), U6.19 (VDD), U6.32 (VDD), U6.48 (VDD), U6.64 (VDD); also elsewhere on the board
ALERT: U6.34 (PB13); also elsewhere on the board
BOOT0: U6.60 (BOOT0); also elsewhere on the board
CS: U6.37 (PC6); also elsewhere on the board
Column0: U6.62 (PB9); also elsewhere on the board
Column1: U6.9 (PC1); also elsewhere on the board
Column2: U6.10 (PC2); also elsewhere on the board
Column3: U6.3 (PC14); also elsewhere on the board
Column4: U6.4 (PC15); also elsewhere on the board
Column5: U6.20 (PA4); also elsewhere on the board
Column6: U6.25 (PC5); also elsewhere on the board
Column7: U6.28 (PB2); also elsewhere on the board
Column8: U6.29 (PB10); also elsewhere on the board
Column9: U6.40 (PC9); also elsewhere on the board
Column10: U6.41 (PA8); also elsewhere on the board
Column11: U6.51 (PC10); also elsewhere on the board
Column12: U6.52 (PC11); also elsewhere on the board
Column13: U6.54 (PD2); also elsewhere on the board
Column14: U6.56 (PB4); also elsewhere on the board
Column15: U6.57 (PB5); also elsewhere on the board
D+: U6.45 (PA12); also elsewhere on the board
D-: U6.44 (PA11); also elsewhere on the board
DC: U6.38 (PC7); also elsewhere on the board
DIN: U6.23 (PA7); also elsewhere on the board
GND: C1.2, C2.2, C3.2, C4.2, C5.2, C8.2, C9.2, C10.2, C11.2, H1.1, R11.1, U4.1 (GND), U4.2 (GND), U4.42 (GND), U4.43 (GND), U4.46 (GND), U4.47 (GND), U4.48 (GND), U4.49 (GND), U4.50 (GND), U4.51 (GND), U4.52 (GND), U4.53 (GND), U4.54 (GND), U4.55 (GND), U4.56 (GND), U4.57 (GND), U4.58 (GND), U4.59 (GND), U4.60 (GND), U4.61 (GND), U4.62 (GND), U4.63 (GND), U4.64 (GND), U4.65 (GND), U6.12 (VSSA), U6.18 (VSS), U6.31 (VSS), U6.47 (VSS), U6.63 (VSS); also elsewhere on the board
NRST: U6.7 (NRST); also elsewhere on the board
unnamed: R2.1, U4.45 (EN)
unnamed: R4.1, U4.4 (IO0)
unnamed: R5.1, R11.2, U6.50 (PA15)
RDY: U6.61 (PB8); also elsewhere on the board
RGB: U6.11 (PC3); also elsewhere on the board
RST: U6.39 (PC8); also elsewhere on the board
RXTX: U4.39 (TXD0), U6.43 (PA10)
Row0: U6.30 (PB11); also elsewhere on the board
Row1: U6.33 (PB12); also elsewhere on the board
Row2: U6.35 (PB14); also elsewhere on the board
Row3: U6.8 (PC0); also elsewhere on the board
Row4: U6.2 (PC13); also elsewhere on the board
SCL: U6.58 (PB6); also elsewhere on the board
SCLK: U6.21 (PA5); also elsewhere on the board
SDA: U6.59 (PB7); also elsewhere on the board
STAT1: U6.53 (PC12); also elsewhere on the board
STAT2: U6.55 (PB3); also elsewhere on the board
TXRX: U4.40 (RXD0), U6.42 (PA9)
VBUS: R5.2; also elsewhere on the board

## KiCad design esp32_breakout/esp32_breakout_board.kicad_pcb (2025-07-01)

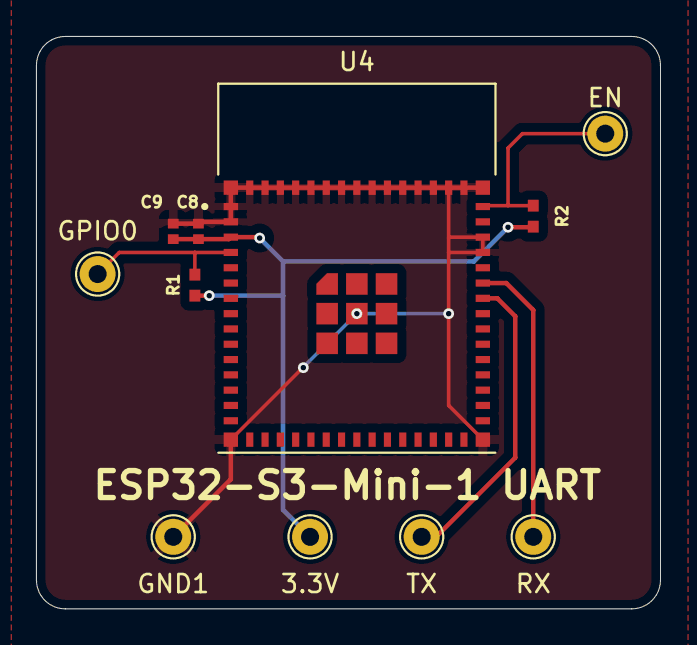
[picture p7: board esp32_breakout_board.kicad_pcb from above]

Board: 2 copper layers, 34.7 x 31.8 mm, 11 parts (0 on the bottom side), 6 nets.

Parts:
3.3V: TestPoint; TestPoint_THTPad_D2.0mm_Drill1.0mm
C8: 10uF; CAPC1005X55N
C9: 100nF; CAPC1005X55N
EN: TestPoint; TestPoint_THTPad_D2.0mm_Drill1.0mm
GND1: TestPoint; TestPoint_THTPad_D2.0mm_Drill1.0mm
GPIO0: TestPoint; TestPoint_THTPad_D2.0mm_Drill1.0mm
R1, R2: 10k; RESC1005X40N
RX: TestPoint; TestPoint_THTPad_D2.0mm_Drill1.0mm
TX: TestPoint; TestPoint_THTPad_D2.0mm_Drill1.0mm
U4: ESP32-S3-MINI-1; XCVR_ESP32-S3-MINI-1-N8

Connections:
+3.3V: 3.3V.1, C8.1, C9.1, R1.2, R2.2, U4.3 (3V3)
EN: EN.1, R2.1, U4.45 (EN)
GND: C8.2, C9.2, GND1.1, U4.1 (GND), U4.2 (GND), U4.42 (GND), U4.43 (GND), U4.46 (GND), U4.47 (GND), U4.48 (GND), U4.49 (GND), U4.50 (GND), U4.51 (GND), U4.52 (GND), U4.53 (GND), U4.54 (GND), U4.55 (GND), U4.56 (GND), U4.57 (GND), U4.58 (GND), U4.59 (GND), U4.60 (GND), U4.61 (GND), U4.62 (GND), U4.63 (GND), U4.64 (GND), U4.65 (GND)
GPIO0: GPIO0.1, R1.1, U4.4 (IO0)
RX: RX.1, U4.40 (RXD0)
TX: TX.1, U4.39 (TXD0)

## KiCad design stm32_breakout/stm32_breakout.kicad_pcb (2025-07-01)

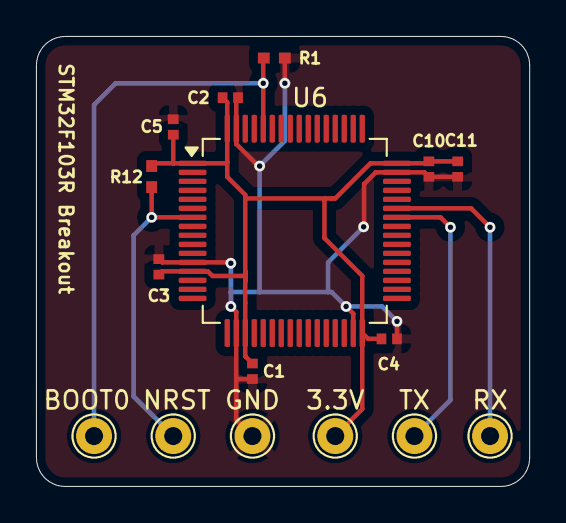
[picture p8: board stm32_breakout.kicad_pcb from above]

Board: 2 copper layers, 27.4 x 25.0 mm, 16 parts (0 on the bottom side), 6 nets.

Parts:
3.3V: TestPoint; TestPoint_THTPad_D2.0mm_Drill1.0mm
BOOT0: TestPoint; TestPoint_THTPad_D2.0mm_Drill1.0mm
C1, C2, C3, C4, C5, C11: 100nF; CAPC1005X55N
C10: 4.7uF; CAPC1005X55N
GND: TestPoint; TestPoint_THTPad_D2.0mm_Drill1.0mm
NRST: TestPoint; TestPoint_THTPad_D2.0mm_Drill1.0mm
R1, R12: 10k; RESC1005X40N
RX: TestPoint; TestPoint_THTPad_D2.0mm_Drill1.0mm
TX: TestPoint; TestPoint_THTPad_D2.0mm_Drill1.0mm
U6: STM32F103RETx; LQFP-64_10x10mm_P0.5mm

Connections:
+3.3V: 3.3V.1, C1.1, C2.1, C3.1, C4.1, C5.1, C10.1, C11.1, R12.2, U6.1 (VBAT), U6.13 (VDDA), U6.19 (VDD), U6.32 (VDD), U6.48 (VDD), U6.64 (VDD)
BOOT0: BOOT0.1, R1.1, U6.60 (BOOT0)
GND: C1.2, C2.2, C3.2, C4.2, C5.2, C10.2, C11.2, GND.1, R1.2, U6.12 (VSSA), U6.18 (VSS), U6.31 (VSS), U6.47 (VSS), U6.63 (VSS)
NRST: NRST.1, R12.1, U6.7 (NRST)
RX: RX.1, U6.43 (PA10)
TX: TX.1, U6.42 (PA9)

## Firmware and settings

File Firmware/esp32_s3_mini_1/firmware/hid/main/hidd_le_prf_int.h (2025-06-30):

/*
 * SPDX-FileCopyrightText: 2021-2022 Espressif Systems (Shanghai) CO LTD
 *
 * SPDX-License-Identifier: Unlicense OR CC0-1.0
 */



#ifndef __HID_DEVICE_LE_PRF__
#define __HID_DEVICE_LE_PRF__
#include <stdbool.h>
#include "esp_gatts_api.h"
#include "esp_gatt_defs.h"
#include "esp_hidd_prf_api.h"
#include "esp_gap_ble_api.h"
#include "hid_dev.h"

#define SUPPORT_REPORT_VENDOR                 false
//HID BLE profile log tag
#define HID_LE_PRF_TAG                        "HID_LE_PRF"

/// Maximal number of HIDS that can be added in the DB
#ifndef USE_ONE_HIDS_INSTANCE
#define HIDD_LE_NB_HIDS_INST_MAX              (2)
#else
#define HIDD_LE_NB_HIDS_INST_MAX              (1)
#endif

#define HIDD_GREAT_VER   0x01  //Version + Subversion
#define HIDD_SUB_VER     0x00  //Version + Subversion
#define HIDD_VERSION     ((HIDD_GREAT_VER<<8)|HIDD_SUB_VER)  //Version + Subversion

#define HID_MAX_APPS                 1

// Number of HID reports defined in the service
#define HID_NUM_REPORTS          9

// HID Report IDs for the service
#define HID_RPT_ID_KEY_IN        2   // Keyboard input report ID
#define HID_RPT_ID_CC_IN         3   //Consumer Control input report ID
#define HID_RPT_ID_VENDOR_OUT    4   // Vendor output report ID
#define HID_RPT_ID_LED_OUT       2  // LED output report ID
#define HID_RPT_ID_FEATURE       0  // Feature report ID

#define HIDD_APP_ID			0x1812//ATT_SVC_HID

#define BATTRAY_APP_ID       0x180f


#define ATT_SVC_HID          0x1812

/// Maximal number of Report Char. that can be added in the DB for one HIDS - Up to 11
#define HIDD_LE_NB_REPORT_INST_MAX            (5)

/// Maximal length of Report Char. Value
#define HIDD_LE_REPORT_MAX_LEN                (255)
/// Maximal length of Report Map Char. Value
#define HIDD_LE_REPORT_MAP_MAX_LEN            (512)

/// Length of Boot Report Char. Value Maximal Length
#define HIDD_LE_BOOT_REPORT_MAX_LEN           (8)

/// Boot KB Input Report Notification Configuration Bit Mask
#define HIDD_LE_BOOT_KB_IN_NTF_CFG_MASK       (0x40)
/// Boot Report Notification Configuration Bit Mask
#define HIDD_LE_REPORT_NTF_CFG_MASK           (0x20)


/* HID information flags */
#define HID_FLAGS_REMOTE_WAKE           0x01      // RemoteWake
#define HID_FLAGS_NORMALLY_CONNECTABLE  0x02      // NormallyConnectable

/* Control point commands */
#define HID_CMD_SUSPEND                 0x00      // Suspend
#define HID_CMD_EXIT_SUSPEND            0x01      // Exit Suspend

/* HID protocol mode values */
#define HID_PROTOCOL_MODE_BOOT          0x00      // Boot Protocol Mode
#define HID_PROTOCOL_MODE_REPORT        0x01      // Report Protocol Mode

/* Attribute value lengths */
#define HID_PROTOCOL_MODE_LEN           1         // HID Protocol Mode
#define HID_INFORMATION_LEN             4         // HID Information
#define HID_REPORT_REF_LEN              2         // HID Report Reference Descriptor
#define HID_EXT_REPORT_REF_LEN          2         // External Report Reference Descriptor

// HID feature flags
#define HID_KBD_FLAGS             HID_FLAGS_REMOTE_WAKE

/* HID Report type */
#define HID_REPORT_TYPE_INPUT       1
#define HID_REPORT_TYPE_OUTPUT      2
#define HID_REPORT_TYPE_FEATURE     3


/// HID Service Attributes Indexes
enum {
    HIDD_LE_IDX_SVC,

    // Included Service
    HIDD_LE_IDX_INCL_SVC,

    // HID Information
    HIDD_LE_IDX_HID_INFO_CHAR,
    HIDD_LE_IDX_HID_INFO_VAL,

    // HID Control Point
    HIDD_LE_IDX_HID_CTNL_PT_CHAR,
    HIDD_LE_IDX_HID_CTNL_PT_VAL,

    // Report Map
    HIDD_LE_IDX_REPORT_MAP_CHAR,
    HIDD_LE_IDX_REPORT_MAP_VAL,
    HIDD_LE_IDX_REPORT_MAP_EXT_REP_REF,

    // Protocol Mode
    HIDD_LE_IDX_PROTO_MODE_CHAR,
    HIDD_LE_IDX_PROTO_MODE_VAL,

    //Report Key input
    HIDD_LE_IDX_REPORT_KEY_IN_CHAR,
    HIDD_LE_IDX_REPORT_KEY_IN_VAL,
    HIDD_LE_IDX_REPORT_KEY_IN_CCC,
    HIDD_LE_IDX_REPORT_KEY_IN_REP_REF,
    ///Report Led output
    HIDD_LE_IDX_REPORT_LED_OUT_CHAR,
    HIDD_LE_IDX_REPORT_LED_OUT_VAL,
    HIDD_LE_IDX_REPORT_LED_OUT_REP_REF,

#if (SUPPORT_REPORT_VENDOR  == true)
    /// Report Vendor
    HIDD_LE_IDX_REPORT_VENDOR_OUT_CHAR,
    HIDD_LE_IDX_REPORT_VENDOR_OUT_VAL,
    HIDD_LE_IDX_REPORT_VENDOR_OUT_REP_REF,
#endif
    HIDD_LE_IDX_REPORT_CC_IN_CHAR,
    HIDD_LE_IDX_REPORT_CC_IN_VAL,
    HIDD_LE_IDX_REPORT_CC_IN_CCC,
    HIDD_LE_IDX_REPORT_CC_IN_REP_REF,

    // Boot Keyboard Input Report
    HIDD_LE_IDX_BOOT_KB_IN_REPORT_CHAR,
    HIDD_LE_IDX_BOOT_KB_IN_REPORT_VAL,
    HIDD_LE_IDX_BOOT_KB_IN_REPORT_NTF_CFG,

    // Boot Keyboard Output Report
    HIDD_LE_IDX_BOOT_KB_OUT_REPORT_CHAR,
    HIDD_LE_IDX_BOOT_KB_OUT_REPORT_VAL,

    // Report
    HIDD_LE_IDX_REPORT_CHAR,
    HIDD_LE_IDX_REPORT_VAL,
    HIDD_LE_IDX_REPORT_REP_REF,
    //HIDD_LE_IDX_REPORT_NTF_CFG,

    HIDD_LE_IDX_NB,
};


/// Attribute Table Indexes
enum {
    HIDD_LE_INFO_CHAR,
    HIDD_LE_CTNL_PT_CHAR,
    HIDD_LE_REPORT_MAP_CHAR,
    HIDD_LE_REPORT_CHAR,
    HIDD_LE_PROTO_MODE_CHAR,
    HIDD_LE_BOOT_KB_IN_REPORT_CHAR,
    HIDD_LE_BOOT_KB_OUT_REPORT_CHAR,
    HIDD_LE_CHAR_MAX //= HIDD_LE_REPORT_CHAR + HIDD_LE_NB_REPORT_INST_MAX,
};

///att read event table Indexs
enum {
    HIDD_LE_READ_INFO_EVT,
    HIDD_LE_READ_CTNL_PT_EVT,
    HIDD_LE_READ_REPORT_MAP_EVT,
    HIDD_LE_READ_REPORT_EVT,
    HIDD_LE_READ_PROTO_MODE_EVT,
    HIDD_LE_BOOT_KB_IN_REPORT_EVT,
    HIDD_LE_BOOT_KB_OUT_REPORT_EVT,

    HID_LE_EVT_MAX
};

/// Client Characteristic Configuration Codes
enum {
    HIDD_LE_DESC_MASK = 0x10,

    HIDD_LE_BOOT_KB_IN_REPORT_CFG     = HIDD_LE_BOOT_KB_IN_REPORT_CHAR | HIDD_LE_DESC_MASK,
    HIDD_LE_REPORT_CFG                = HIDD_LE_REPORT_CHAR | HIDD_LE_DESC_MASK,
};

/// Features Flag Values
enum {
    HIDD_LE_CFG_KEYBOARD      = 0x01,
    HIDD_LE_CFG_PROTO_MODE    = 0x04,
    HIDD_LE_CFG_MAP_EXT_REF   = 0x08,
    HIDD_LE_CFG_BOOT_KB_WR    = 0x10,
};

/// Report Char. Configuration Flag Values
enum {
    HIDD_LE_CFG_REPORT_IN     = 0x01,
    HIDD_LE_CFG_REPORT_OUT    = 0x02,
    //HOGPD_CFG_REPORT_FEAT can be used as a mask to check Report type
    HIDD_LE_CFG_REPORT_FEAT   = 0x03,
    HIDD_LE_CFG_REPORT_WR     = 0x10,
};

/// Pointer to the connection clean-up function
#define HIDD_LE_CLEANUP_FNCT        (NULL)

/*
 * TYPE DEFINITIONS
 ****************************************************************************************
 */

/// HIDD Features structure
typedef struct {
    /// Service Features
    uint8_t svc_features;
    /// Number of Report Char. instances to add in the database
    uint8_t report_nb;
    /// Report Char. Configuration
    uint8_t report_char_cfg[HIDD_LE_NB_REPORT_INST_MAX];
} hidd_feature_t;


typedef struct {
    bool                        in_use;
    bool                        congest;
    uint16_t                  conn_id;
    bool                        connected;
    esp_bd_addr_t         remote_bda;
    uint32_t                  trans_id;
    uint8_t                    cur_srvc_id;

} hidd_clcb_t;
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

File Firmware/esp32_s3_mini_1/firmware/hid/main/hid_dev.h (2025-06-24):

/*
 * SPDX-FileCopyrightText: 2021-2022 Espressif Systems (Shanghai) CO LTD
 *
 * SPDX-License-Identifier: Unlicense OR CC0-1.0
 */

#ifndef HID_DEV_H__
#define HID_DEV_H__

#include "hidd_le_prf_int.h"


#ifdef __cplusplus
extern "C" {
#endif


/* HID Report type */
#define HID_TYPE_INPUT       1
#define HID_TYPE_OUTPUT      2
#define HID_TYPE_FEATURE     3

// HID Keyboard/Keypad Usage IDs (subset of the codes available in the USB HID Usage Tables spec)
#define HID_KEY_RESERVED       0    // No event inidicated
#define HID_KEY_A              4    // Keyboard a and A
#define HID_KEY_B              5    // Keyboard b and B
#define HID_KEY_C              6    // Keyboard c and C
#define HID_KEY_D              7    // Keyboard d and D
#define HID_KEY_E              8    // Keyboard e and E
#define HID_KEY_F              9    // Keyboard f and F
#define HID_KEY_G              10   // Keyboard g and G
#define HID_KEY_H              11   // Keyboard h and H
#define HID_KEY_I              12   // Keyboard i and I
#define HID_KEY_J              13   // Keyboard j and J
#define HID_KEY_K              14   // Keyboard k and K
#define HID_KEY_L              15   // Keyboard l and L
#define HID_KEY_M              16   // Keyboard m and M
#define HID_KEY_N              17   // Keyboard n and N
#define HID_KEY_O              18   // Keyboard o and O
#define HID_KEY_P              19   // Keyboard p and p
#define HID_KEY_Q              20   // Keyboard q and Q
#define HID_KEY_R              21   // Keyboard r and R
#define HID_KEY_S              22   // Keyboard s and S
#define HID_KEY_T              23   // Keyboard t and T
#define HID_KEY_U              24   // Keyboard u and U
#define HID_KEY_V              25   // Keyboard v and V
#define HID_KEY_W              26   // Keyboard w and W
#define HID_KEY_X              27   // Keyboard x and X
#define HID_KEY_Y              28   // Keyboard y and Y
#define HID_KEY_Z              29   // Keyboard z and Z
#define HID_KEY_1              30   // Keyboard 1 and !
#define HID_KEY_2              31   // Keyboard 2 and @
#define HID_KEY_3              32   // Keyboard 3 and #
#define HID_KEY_4              33   // Keyboard 4 and %
#define HID_KEY_5              34   // Keyboard 5 and %
#define HID_KEY_6              35   // Keyboard 6 and ^
#define HID_KEY_7              36   // Keyboard 7 and &
#define HID_KEY_8              37   // Keyboard 8 and *
#define HID_KEY_9              38   // Keyboard 9 and (
#define HID_KEY_0              39   // Keyboard 0 and )
#define HID_KEY_RETURN         40   // Keyboard Return (ENTER)
#define HID_KEY_ESCAPE         41   // Keyboard ESCAPE
#define HID_KEY_DELETE         42   // Keyboard DELETE (Backspace)
#define HID_KEY_TAB            43   // Keyboard Tab
#define HID_KEY_SPACEBAR       44   // Keyboard Spacebar
#define HID_KEY_MINUS          45   // Keyboard - and (underscore)
#define HID_KEY_EQUAL          46   // Keyboard = and +
#define HID_KEY_LEFT_BRKT      47   // Keyboard [ and {
#define HID_KEY_RIGHT_BRKT     48   // Keyboard ] and }
#define HID_KEY_BACK_SLASH     49   // Keyboard \ and |
#define HID_KEY_SEMI_COLON     51   // Keyboard ; and :
#define HID_KEY_SGL_QUOTE      52   // Keyboard ' and "
#define HID_KEY_GRV_ACCENT     53   // Keyboard Grave Accent and Tilde
#define HID_KEY_COMMA          54   // Keyboard , and <
#define HID_KEY_DOT            55   // Keyboard . and >
#define HID_KEY_FWD_SLASH      56   // Keyboard / and ?
#define HID_KEY_CAPS_LOCK      57   // Keyboard Caps Lock
#define HID_KEY_F1             58   // Keyboard F1
#define HID_KEY_F2             59   // Keyboard F2
#define HID_KEY_F3             60   // Keyboard F3
#define HID_KEY_F4             61   // Keyboard F4
#define HID_KEY_F5             62   // Keyboard F5
#define HID_KEY_F6             63   // Keyboard F6
#define HID_KEY_F7             64   // Keyboard F7
#define HID_KEY_F8             65   // Keyboard F8
#define HID_KEY_F9             66   // Keyboard F9
#define HID_KEY_F10            67   // Keyboard F10
#define HID_KEY_F11            68   // Keyboard F11
#define HID_KEY_F12            69   // Keyboard F12
#define HID_KEY_PRNT_SCREEN    70   // Keyboard Print Screen
#define HID_KEY_SCROLL_LOCK    71   // Keyboard Scroll Lock
#define HID_KEY_PAUSE          72   // Keyboard Pause
#define HID_KEY_INSERT         73   // Keyboard Insert
#define HID_KEY_HOME           74   // Keyboard Home
#define HID_KEY_PAGE_UP        75   // Keyboard PageUp
#define HID_KEY_DELETE_FWD     76   // Keyboard Delete Forward
#define HID_KEY_END            77   // Keyboard End
#define HID_KEY_PAGE_DOWN      78   // Keyboard PageDown
#define HID_KEY_RIGHT_ARROW    79   // Keyboard RightArrow
#define HID_KEY_LEFT_ARROW     80   // Keyboard LeftArrow
#define HID_KEY_DOWN_ARROW     81   // Keyboard DownArrow
#define HID_KEY_UP_ARROW       82   // Keyboard UpArrow
#define HID_KEY_NUM_LOCK       83   // Keypad Num Lock and Clear
#define HID_KEY_DIVIDE         84   // Keypad /
#define HID_KEY_MULTIPLY       85   // Keypad *
#define HID_KEY_SUBTRACT       86   // Keypad -
#define HID_KEY_ADD            87   // Keypad +
#define HID_KEY_ENTER          88   // Keypad ENTER
#define HID_KEYPAD_1           89   // Keypad 1 and End
#define HID_KEYPAD_2           90   // Keypad 2 and Down Arrow
#define HID_KEYPAD_3           91   // Keypad 3 and PageDn
#define HID_KEYPAD_4           92   // Keypad 4 and Lfet Arrow
#define HID_KEYPAD_5           93   // Keypad 5
#define HID_KEYPAD_6           94   // Keypad 6 and Right Arrow
#define HID_KEYPAD_7           95   // Keypad 7 and Home
#define HID_KEYPAD_8           96   // Keypad 8 and Up Arrow
#define HID_KEYPAD_9           97   // Keypad 9 and PageUp
#define HID_KEYPAD_0           98   // Keypad 0 and Insert
#define HID_KEYPAD_DOT         99   // Keypad . and Delete
#define HID_KEY_MUTE           127  // Keyboard Mute
#define HID_KEY_VOLUME_UP      128  // Keyboard Volume up
#define HID_KEY_VOLUME_DOWN    129  // Keyboard Volume down
#define HID_KEY_LEFT_CTRL      224  // Keyboard LeftContorl
#define HID_KEY_LEFT_SHIFT     225  // Keyboard LeftShift
#define HID_KEY_LEFT_ALT       226  // Keyboard LeftAlt
#define HID_KEY_LEFT_GUI       227  // Keyboard LeftGUI
#define HID_KEY_RIGHT_CTRL     228  // Keyboard RightContorl
#define HID_KEY_RIGHT_SHIFT    229  // Keyboard RightShift
#define HID_KEY_RIGHT_ALT      230  // Keyboard RightAlt
#define HID_KEY_RIGHT_GUI      231  // Keyboard RightGUI
typedef uint8_t keyboard_cmd_t;



// HID Consumer Usage IDs (subset of the codes available in the USB HID Usage Tables spec)
#define HID_CONSUMER_POWER          48  // Power
#define HID_CONSUMER_RESET          49  // Reset
#define HID_CONSUMER_SLEEP          50  // Sleep
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

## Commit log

2025-04-06 v1.0 pcb
    Constructed v1.0 of PCB, just 65% layout keys
    [pcb_v1.kicad_pcb, pcb_v1.kicad_sch]
2025-04-07 Added footprints for LEDs, Rotary Encoder
    [leds.kicad_sch, pcb.kicad_sch, pcb_v1.kicad_pcb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]
2025-04-07 Included Capacitors and JST connector in schematic. Upgraded MC to 69 pin version
    [leds.kicad_sch, pcb_v1.kicad_pcb, pcb_v1.kicad_sch]
2025-04-08 Added Flex Cuts
    [pcb.kicad_sch, pcb_v1.kicad_pcb, pcb_v1.kicad_sch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]
2025-04-08 Re-drew PCB. Flipped to the correct orientation
    [pcb_v1.kicad_pcb, pcb_v1.kicad_sch, recharge_circuit.kicad_sch]
2025-04-09 Basic Routing around flex cuts
    [pcb_v1.kicad_pcb]
2025-04-10 New LED Schematic
    [leds.kicad_sch, pcb_v1.kicad_pcb]
2025-04-10 Replaced and wired LEDs and Capacitors
    [leds.kicad_sch, pcb_v1.kicad_pcb]
2025-04-11 Daisy Chained LEDs
    [pcb_v1.kicad_pcb]
2025-04-11 Added 5V connectors to LEDs
    [pcb_v1.kicad_pcb]
2025-04-11 Drew in Main 5V lines
    [pcb_v1.kicad_pcb]
2025-04-11 All 5V LEDs are connected
    [pcb_v1.kicad_pcb]
2025-04-11 Drew Main Ground Line
    [pcb_v1.kicad_pcb]
2025-04-11 Fixed Via Sizes
    [leds.kicad_sch, pcb_v1.kicad_pcb]
2025-04-11 Clearance fixes
    [pcb_v1.kicad_pcb]
2025-04-13 Connected all switches, LEDs to MCU
    [leds.kicad_sch, pcb_v1.kicad_pcb, pcb_v1.kicad_sch]
2025-04-13 Routed trace to rotary encoder
    [pcb_v1.kicad_pcb, pcb_v1.kicad_sch]
2025-04-13 Added Decoupling Capacitors
    [pcb.kicad_sch, pcb_v1.kicad_pcb, pcb_v1.kicad_sch]
2025-04-14 Added ESP Protection
    [pcb_v1.kicad_pcb, pcb_v1.kicad_sch]
2025-04-20 Wiring Update
    [OLED.kicad_sch, Power.kicad_sch, pcb.kicad_sch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]
2025-04-26 New MCU. Added ESP32 S3 Mini1 to act as Bluetooth module
    [MCU.kicad_sch, Power.kicad_sch, pcb_v1.kicad_sch]
2025-04-28 Updated wiring
    [MCU.kicad_sch, Power.kicad_sch, leds.kicad_sch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]
2025-04-28 Added basic firmware files for esp32
2025-04-28 Create BOM
    [BOM.xlsx]
2025-04-29 Update Wiring
    [MCU.kicad_sch, pcb_v1.kicad_pcb, pcb_v1.kicad_sch]
2025-04-30 Wired all keyboard matrix pins
    [BOM.xlsx, MCU.kicad_sch, leds.kicad_sch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]
2025-05-02 Connected OLED pin connector
    [BOM.xlsx, MCU.kicad_sch, Power.kicad_sch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]
2025-05-18 Changed Layout of Keyboard
    Row 1, Column 14 Removed due to OLED Screen taking up 2x2 u space
    [MCU.kicad_sch, leds.kicad_sch, pcb.kicad_sch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]
2025-05-19 Finished PCB Framework Design
    [pcb_v1.kicad_pcb]
2025-05-24 Changed PCB to Accommodate Revised Layout
    Added a few more keys to balance the screen being 2u x 2u, therefore extending the length of the PCB
    [MCU.kicad_sch, leds.kicad_sch, pcb.kicad_sch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]
2025-05-29 New Charger IC, Added Ground Plane
    [BOM.xlsx, MCU.kicad_sch, Power.kicad_sch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]
2025-05-29 Update BOM
    [BOM.xlsx, pcb.kicad_sch]
2025-05-30 Added initial QMK files
    [bom.csv, designators.csv, positions.csv]
2025-06-01 Reposition IQS624
    [MCU.kicad_sch, positions.csv]
2025-06-07 Updated thru holes and connector sizings
    [Power.kicad_sch, pcb_v1.kicad_pcb, pcb_v1.kicad_sch]
2025-06-12 Finished 4 layer design
    [MCU.kicad_sch, Power.kicad_sch]
2025-06-14 Changed gasket mounts and added keepout zone for esp32
    [BOM.xlsx, Power.kicad_sch, bom.csv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]
2025-06-17 Added thermal net for AMS1117-3.3
    [pcb_v1.kicad_pcb]
2025-06-19 Reverse polarity on pins
    [MCU.kicad_sch, Power.kicad_sch, pcb_v1.kicad_pcb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]
2025-06-20 Made flex cuts longer
    [pcb_v1.kicad_pcb]
2025-06-21 Creation of breakout boards for stm32 and esp32 flashing
    [bom.csv, esp32_breakout_board.kicad_pcb, esp32_breakout_board.kicad_sch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]
2025-06-22 Included resistors for EN/GPIO0 on ESP32
    [MCU.kicad_sch, bom.csv, designators.csv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]
2025-06-24 Update Breakout board designs
    [bom.csv, designators.csv, esp32_breakout_board.kicad_pcb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]
2025-06-24 Edited Firmware for ESP32
2025-06-30 esp32 v1.0
2025-06-30 Revived ESP32 Breakout Board
    [bom.csv, designators.csv, esp32_breakout_board.kicad_pcb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]
2025-06-30 Updated esp32 breakout board
    [bom.csv, designators.csv, esp32_breakout_board.kicad_pcb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]
2025-07-01 Added silkscreen to boards
    [bom.csv, designators.csv, esp32_breakout_board.kicad_pcb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]
2025-07-01 Prettied up traces on PCB
    [pcb_v1.kicad_pcb]
2025-07-01 Added Plate Mounting Screw Holes in PCB
    [pcb_v1.kicad_pcb]
2025-07-02 Added more silkscreen to the pcb
    [pcb_v1.kicad_pcb]
2025-07-02 Re-located one screw hole for plate screw
    [pcb_v1.kicad_pcb]
